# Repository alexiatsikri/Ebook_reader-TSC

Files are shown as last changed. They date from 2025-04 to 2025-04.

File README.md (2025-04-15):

# Ebook_reader-TSC

## Pasi de implementare
1. Analiza documentatiei initiale
- Am urmarit schematicul si board layout-ul furnizate de profesor.
- Pe baza acestora, am reprodus designul electronic in Fusion Electronics, atat schematicul, cat si placa PCB.
2. Plasarea componentelor in PCB
- Am inceput sa asez componentele pe placa, respectand pozitionarea si orientarea optima pentru un traseu eficient si functional.
3. Rutarea traseelor
- Am efectuat manual rutarea traseelor de putere, pentru a ma asigura ca acestea sunt robuste si bine dimensionate.
- Pentru restul conexiunilor, am utilizat functia de autorouting pe ambele straturi: top si bottom.
- Am adaugat polygon pour pentru ambele straturi, pentru a realiza plane de masa.
4. Optimizarea layout-ului
- Am utilizat vias pentru a conecta planele de masa intre straturi si a completa zonele neconectate.
- Am aplicat via stitching pentru a imbunatati integritatea electrica.
5. Generarea modelului 3D al placii
- Am creat modelul 3D al placii pe baza designului 2D.
- Pentru aceasta, am cautat, descarcat si importat manual fiecare componenta 3D, apoi le-am pozitionat conform plasamentului din PCB-ul 2D.
- Pentru componenta test pad, nu am gasit un model 3D disponibil online, asa ca am fost nevoita sa il modelez manual, pentru a putea reprezenta corect placa in ansamblul 3D.
6. Integrarea in ansamblul final – Openbook Enclosure
- Am importat modelul 3D al placii in fisierul principal al carcasei: Openbook Enclosure.
- In acest fisier am plasat toate componentele in carcasa finala, astfel incat sa asigur o potrivire optima si functionala.
- Am desenat manual display-ul si bateria, pentru a le integra in ansamblu si a obtine o reprezentare cat mai realista a produsului final.

## Block Diagram

Diagrama bloc

## Bill of Materials
| Componenta | Link | Datasheet |
|---|---|---|
| Buton | [Model](https://industry.panasonic.com/global/en/products/control/switch/light-touch/number/evqpuj02k) | [Datasheet](https://www.lcsc.com/datasheet/lcsc_datasheet_2201121800_PANASONIC-EVQPUJ02K_C2936858.pdf) |
| Capacitor | [Model](https://componentsearchengine.com/part-view/R0402%201%25%20100%20K%20(RC0402FR-07100KL)/YAGEO) | [Datasheet](//efaidnbmnnnibpcajpcglclefindmkaj/https://www.resistor.com/assets/pdf/0402tstd.pdf) |
| CPH3225A | [Model](https://www.snapeda.com/parts/CPH3225A/Seiko+Instruments/view-part/?ref=eda) | [Datasheet](https://octopart.com/datasheet/cph3225a-seiko-25340571) |
| EVQPUJ02K | [Model](https://industry.panasonic.com/global/en/products/control/switch/light-touch/number/evqpuj02k) | [Datasheet](https://www.lcsc.com/datasheet/lcsc_datasheet_2201121800_PANASONIC-EVQPUJ02K_C2936858.pdf) |
| KP-1608SURCK | [Model](https://www.snapeda.com/parts/KP-1608SURCK/Kingbright/view-part/?ref=search&t=LED%200603) | [Datasheet](//efaidnbmnnnibpcajpcglclefindmkaj/https://media.elv.com/file/107153_led_surck1608_data.pdf) |
| USBLC6-2SC6Y | [Model](https://www.snapeda.com/parts/USBLC6-2SC6Y/STMicroelectronics/view-part/?ref=eda) | [Datasheet](https://www.digikey.com/en/htmldatasheets/production/1375342/0/0/1/usblc6-2sc6y) |
| SD0805S020S1R0 | [Model](https://ro.mouser.com/ProductDetail/KYOCERA-AVX/SD0805S020S1R0?qs=jCA%252BPfw4LHbpkAoSnwrdjw%3D%3D) | [Datasheet](https://www.alldatasheet.com/view.jsp?Searchword=SD0805S&sField=2) |
| PGB1010603MR | [Model](https://www.snapeda.com/parts/PGB1010603MR/Littelfuse/view-part/?ref=eda) | [Datasheet](https://www.alldatasheet.com/view.jsp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) |
| BD5229G-TR  | [Model](https://componentsearchengine.com/part-view/BD5229G-TR/ROHM%20Semiconductor) | [Datasheet](https://www.lcsc.com/datasheet/lcsc_datasheet_2201131330_ROHM-Semicon-BD5229G-TR_C962636.pdf) |
| XC6220A331MR-G | [Model](https://componentsearchengine.com/part-view/XC6220A331MR-G/Torex) | [Datasheet](https://www.alldatasheet.com/view.jsp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) |
| XC6220A331MR-G | [Model](https://componentsearchengine.com/part-view/XC6220A331MR-G/Torex) | [Datasheet](https://www.alldatasheet.com/view.jsp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) |
| USB4110-GF-A  | [Model](https://componentsearchengine.com/part-view/USB4110-GF-A/GCT%20(GLOBAL%20CONNECTOR%20TECHNOLOGY)) | [Datasheet](//efaidnbmnnnibpcajpcglclefindmkaj/https://gct.co/files/drawings/usb4110.pdf) |
| Adafruit | [Model](https://eu.mouser.com/ProductDetail/Adafruit/4208?qs=PzGy0jfpSMtbScLbr0L5dw%3D%3D) | [Datasheet](https://www.arrow.com/en/manufacturers/adafruit-industries/datasheets) |
| Bobina | [Model](https://store.comet.srl.ro/Catalogue/Product/43497/) | [Datasheet](https://www.scribd.com/document/814581278/Datasheet-Bobina) |
| PFMF | [Model](https://www.mouser.co.uk/ProductDetail/EPCOS-TDK/B72520T0350K062?qs=dEfas%2FXlABIszF52uu7vrg%3D%3D) | [Datasheet](https://ro.mouser.com/c/ds/circuit-protection/thermistors/resettable-fuses-pptc/?m=Schurter&series=PFMF) |
| DMG2305UX-7 | [Model](https://componentsearchengine.com/part-view/DMG2305UX-7/Diodes%20Incorporated) | [Datasheet](//efaidnbmnnnibpcajpcglclefindmkaj/https://www.mouser.com/datasheet/2/115/DMG2305UX-266242.pdf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) |
| Si1308EDL-T1-GE3 | [Model](https://componentsearchengine.com/part-view/SI1308EDL-T1-GE3/Vishay) | [Datasheet](https://www.alldatasheet.com/view.jsp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) |
| R0402 | [Model](https://componentsearchengine.com/part-view/R0402%201%25%20100%20K%20(RC0402FR-07100KL)/YAGEO) | [Datasheet](//efaidnbmnnnibpcajpcglclefindmkaj/https://www.resistor.com/assets/pdf/0402tstd.pdf) |
| BME680 | [Model](https://www.snapeda.com/parts/BME680/Bosch/view-part/?welcome=home) | [Datasheet](//efaidnbmnnnibpcajpcglclefindmkaj/https://www.bosch-sensortec.com/media/boschsensortec/downloads/datasheets/bst-bme680-ds001.pdf) |
| SMD Solder | [Model](https://grabcad.com/library/solder-jumpers-1) | [Datasheet]() |
| W25Q512JVEIQ | [Model](https://www.snapeda.com/parts/ESP32-C6-WROOM-1-N8/Espressif+Systems/view-part/?ref=eda) | [Datasheet](//efaidnbmnnnibpcajpcglclefindmkaj/https://www.mouser.com/datasheet/2/949/W25Q512JV_SPI_RevB_06252019_KMS-2487502.pdf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) |
| ESP32-C6-WROOM-1-N8 | [Model](https://www.snapeda.com/parts/ESP32-C6-WROOM-1-N8/Espressif+Systems/view-part/?ref=eda) | [Datasheet](//efaidnbmnnnibpcajpcglclefindmkaj/https://www.mouser.com/catalog/specsheets/Espressif_ESP32_C6_WROOM_1%20_Datasheet_V0.1_PRELIMINARY_en.pdf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) |
| DS3231SN# | [Model](https://www.snapeda.com/parts/DS3231SN%23/Analog+Devices/view-part/?ref=eda) | [Datasheet](https://www.alldatasheet.com/view.jsp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) |
| MAX17048G+T10 | [Model](https://www.snapeda.com/parts/MAX17048G+T10/Analog+Devices/view-part/?ref=eda) | [Datasheet](https://www.alldatasheet.com/view.jsp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) |
| MCP73831T-5ACI/OT | [Model](https://www.mouser.co.uk/ProductDetail/Microchip-Technology/MCP73831T-5ACI-OT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) | [Datasheet](//efaidnbmnnnibpcajpcglclefindmkaj/https://ww1.microchip.com/downloads/en/DeviceDoc/MCP73831-Family-Data-Sheet-DS20001984H.pdf) |

## Functionalitate Hardware

Proiectul are la baza un circuit electronic compact, conceput pentru un dispozitiv de tip E-Book. Componentele principale sunt:

###  USB-C + Protectie ESD
- Asigura alimentarea dispozitivului.
- Se conecteaza prin interfata USB.
- Include protectie ESD pentru siguranta suplimentara.

###  SD Card
- Serveste ca mediu de stocare pentru cartile electronice.
- Functioneaza la 3.3V si comunica prin SPI cu microcontrollerul.

###  E-Paper Display + Module Asociate
- Include E-Paper Drive Circuit, Display Header si modulul EPD Power.
- Display Header se conecteaza la microcontroller prin SPI.
- EPD Power genereaza tensiunile necesare, iar Drive Circuit furnizeaza semnalele de control.
- Consum maxim la refresh: 30mA (alb-negru) / 60mA (color); consum zero in inactivitate.

### Senzor de Mediu - BME688
- Masoara temperatura, umiditate, presiune si calitatea aerului.
- Comunica prin I2C si functioneaza la 3.3V.
- Consum: <1uA in standby, 1–2mA in functionare.

### Modul RTC - DS3231SN
- Pastreaza ora si data curenta chiar si cu microcontrollerul oprit.
- Functioneaza pe baterie, cristal integrat de 32KHz.
- Comunica prin I2C.
- Consum: 150uA normal, 1uA pe baterie.

###  Memorie Flash Externa - 64MB NOR
- Extinde spatiul de stocare al microcontrollerului.
- Interfata SPI.
- Consum redus: 30–50mA la scriere/stergere, 10–20uA in standby.

###  Regulator de Tensiune LDO
- Asigura 3.3V pentru microcontroller.
- Consum foarte mic (~8uA activ), ideal pentru dispozitive pe baterii.

###  Supraveghetor de Tensiune
- Monitorizeaza stabilitatea tensiunii.
- Previne pornirea in conditii de tensiune necorespunzatoare.

###  Conector Qwiic/Stemma QT
- Permite conectarea facila a senzorilor prin I2C.
- Suporta conectarea in lant fara cabluri suplimentare.

###  Controler Baterie Li-Po
- Gestioneaza incarcarea/descarcarea bateriei.
- Previne suprasarcina si descarcarea profunda.

## Microcontroller - ESP32-C5

Platforma principala este modulul **ESP32-C5-WROOM**, un microcontroller performant cu consum redus, conectivitate moderna si suport pentru multiple interfete:

- **Consum energetic estimat:**
  - Activ: 100–120mA
  - Idle: 10–15mA
  - Deep Sleep: 10–20uA
- **Conectivitate:** Wi-Fi 6 (2.4 GHz), Bluetooth 5, USB nativ
- **Interfete:** GPIO, SPI, I2C, UART

### Conexiuni ESP32-C6

| Functie | Pini ESP32-C6 |
|---|---|
| Alimentare & Reset | 3V3, GND, EN |
| USB-C | GPIO13 (USB_D+), GPIO14 (USB_D-) |
| SD Card (SPI) | GPIO27 (MISO), GPIO7 (MOSI), GPIO6 (SCK), GPIO4 (SS_SD) |
| E-Paper Display | GPIO11 (EPD_CS), GPIO5 (EPD_DC), GPIO21 (EPD_RST), GPIO26 (EPD_BUSY) |
| Senzor BME688 (I2C) | GPIO19 (SDA), GPIO20 (SCL), GPIO17 (I2C_PW) |
| UART | TXD0, RXD0 |
| Flash Extern | FLASH_CS |
| Alte functii | IO/BOOT, RTC_PWM, RTC_RST, INT_RTC |

## Design PCB & Amplasare Componente

Amplasarea componentelor pe placa a fost realizata cu grija, respectand bune practici pentru performanta si fiabilitate:

- **ESP32-C6** – pozitionat sus, cu antena orientata spre exterior si zona PCB decupata pentru semnal clar.
- **USB-C** – centrat in partea de jos, aliniat cu carcasa.
- **Display Header** – lateral, cu decupaj dedicat pentru ribbon.
- **Qwiic Connector** – pe margine, spatiu suficient pentru conectare facila.
- **Baterie** – PCB decupat pentru a acomoda dimensiunea bateriei Li-Po.
  
 ## Erori

  La editarea PCB-ului am intampinat urmatoarele erori:
  
- Smd, Copper Width - Net Class: 1 POWER
- Smd-Hole, Board Outline Clearance
 Smd-Hole, Board Outline Clearance

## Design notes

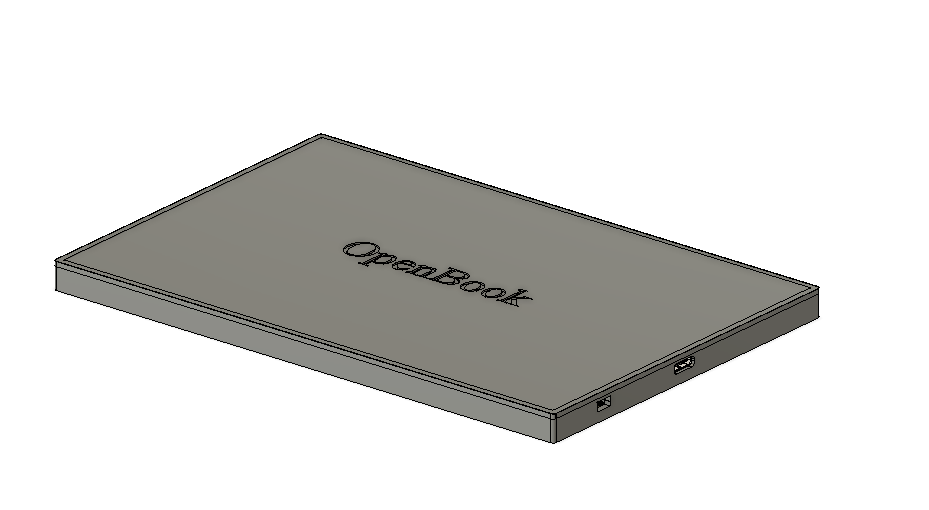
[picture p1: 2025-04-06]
Images/Top-board.png

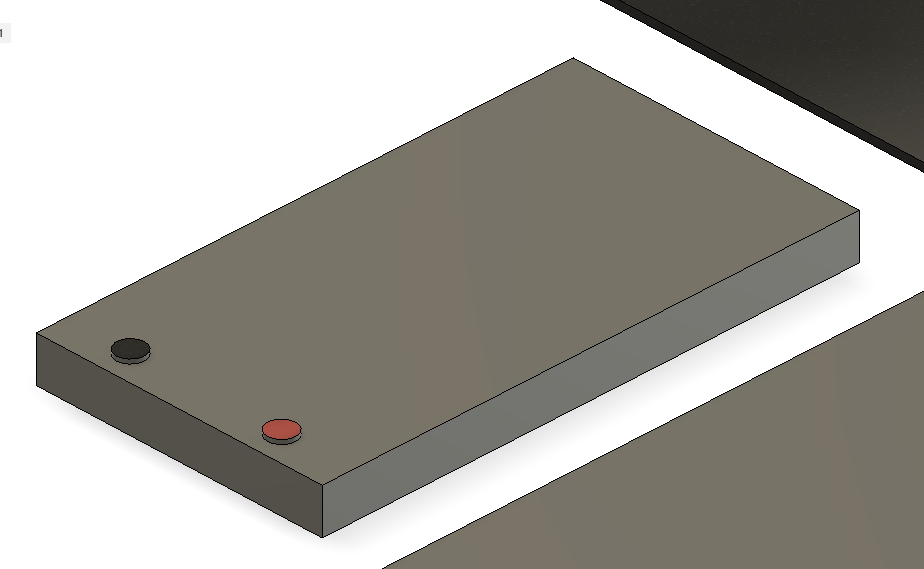
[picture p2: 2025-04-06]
Images/Battery.png

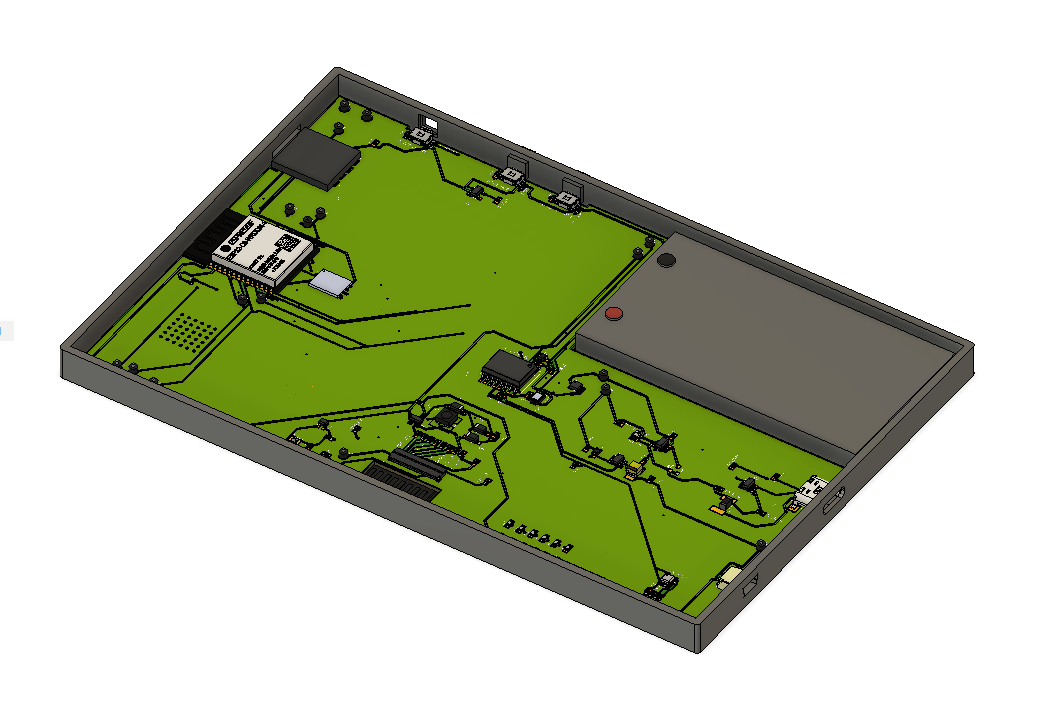
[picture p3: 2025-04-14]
Images/Top-board-no-lid-UPDATE.png

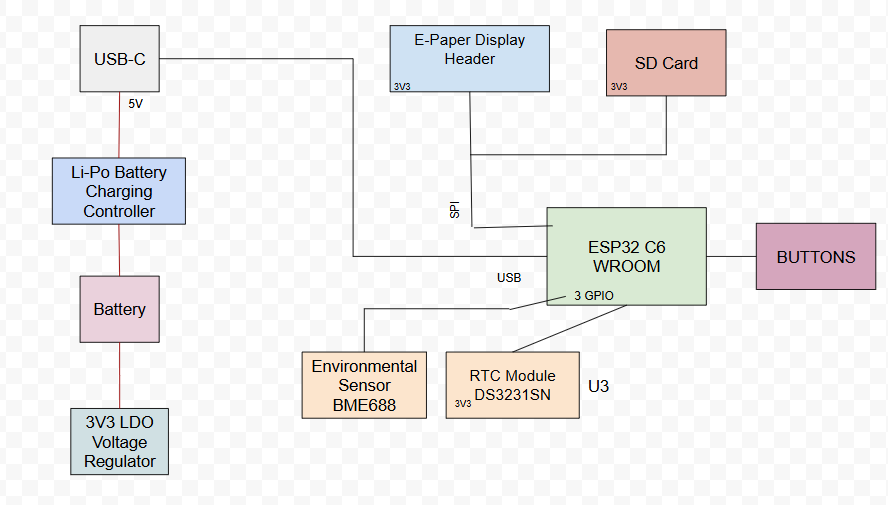
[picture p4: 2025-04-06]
Images/Diagrama bloc.png

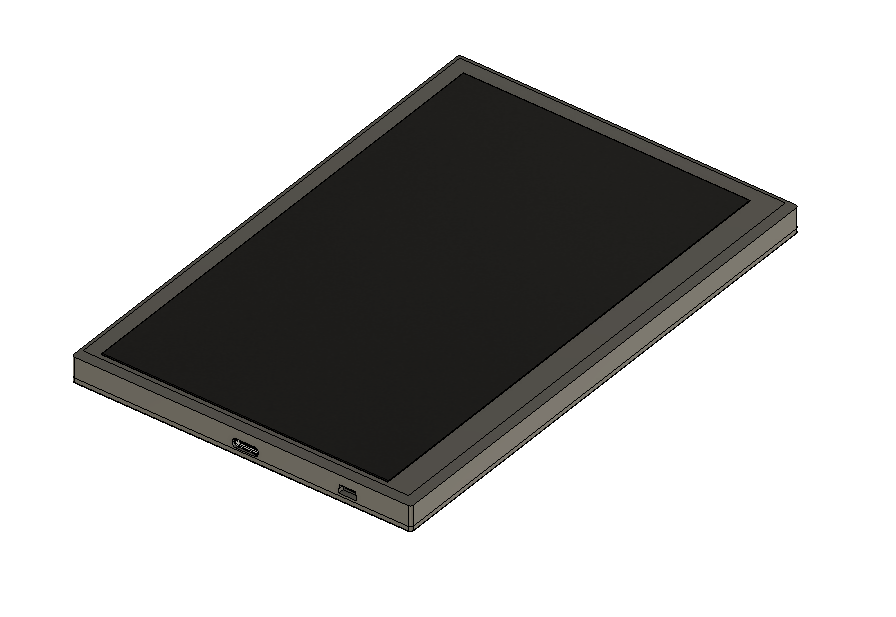
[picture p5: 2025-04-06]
Images/Bottom-board.png

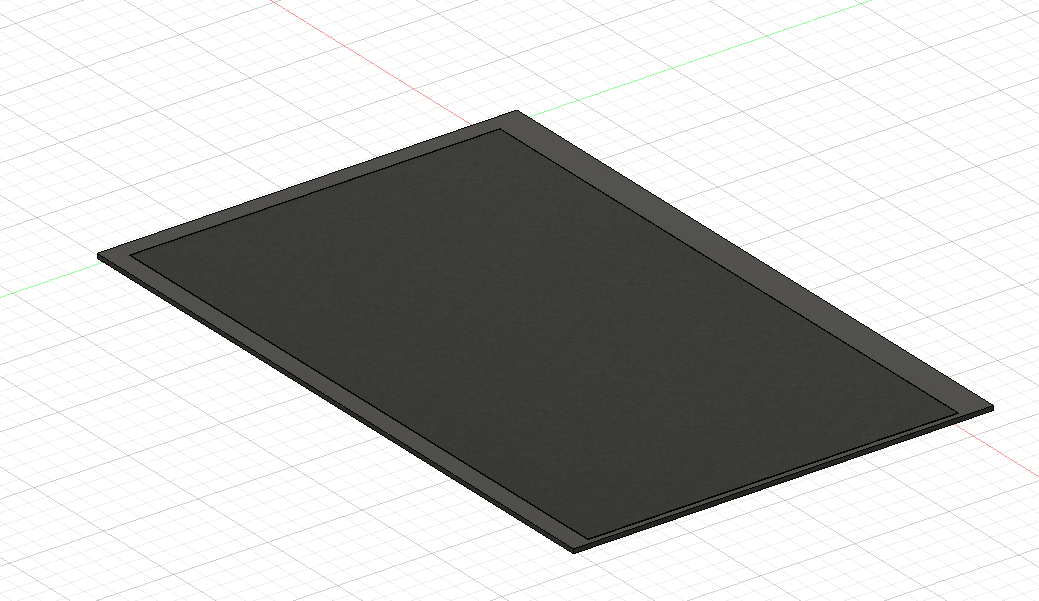
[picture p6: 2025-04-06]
Images/Display.png

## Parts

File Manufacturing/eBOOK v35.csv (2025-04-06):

Qty | Value | Device | Package | Parts | Description | ARROW_PART_NUMBER | ARROW_PRICE-STOCK | AVAILABILITY | CENTROID_NOT_SPECIFIED | CHECK_PRICES | COPYRIGHT | DATASHEET | DESCRIPTION | DIGIKEY_DESCRIPTION | DIGIKEY_PART_NUMBER | HEIGHT | LEAD_FREE | MANUFACTURER_NAME | MANUFACTURER_PART_NUMBER | MF | MFR_NAME | MOUSER_PART_NUMBER | MOUSER_PRICE-STOCK | MOUSER_TESTING_PART_NUMBER | MOUSER_TESTING_PRICE-STOCK | MP | MPN | PACKAGE | POPULARITY | PREFIX | PRICE | PROD_ID | PURCHASE-URL | ROHS | SNAPEDA_LINK | SPICEMODEL | SPICEPREFIX | TEMPERATURE_RANGE_HIGH | TEMPERATURE_RANGE_LOW | TP_SIGNAL_NAME | VALUE
1 |  | ADAFRUIT_LEDCHIP-LED0603 | ADAFRUIT_CHIP-LED0603 | CHG_LED | LED |  |  |  |  | https://www.snapeda.com/parts/KP-1608SURCK/Kingbright/view-part/?ref=search&t=LED%200603
1 |  | SJ | SJ | SJ1 | SMD solder JUMPER |  |  |  |  | https://grabcad.com/library/solder-jumpers-1 |  |  |  |  |  |  |  |  |  |  |  |  |  |  |  |  |  |  | 3
1 | 0.1uF/50V | ESP32_WROVER_EAGLE-LTSPICE_CC0402 | ESP32_WROVER_EAGLE-LTSPICE_C0402 | EPD_C5 | CAPACITOR, European symbol |  |  |  |  | https://componentsearchengine.com/part-view/CC0402MRX5R5BB106/YAGEO |  |  |  |  |  |  |  |  |  |  |  |  |  |  |  |  |  |  |  |  |  |  |  |  |  | NONE | C
1 | 0.47 | ESP32_WROVER_EAGLE-LTSPICE_RR0402 | ESP32_WROVER_EAGLE-LTSPICE_R0402 | R3 | RESISTOR, European symbol |  |  |  |  | https://componentsearchengine.com/part-view/R0402%201%25%20100%20K%20(RC0402FR-07100KL)/YAGEO |  |  |  |  |  |  |  |  |  |  |  |  |  |  |  |  |  |  |  |  |  |  |  |  |  | NONE | R
1 | 100K | ESP32_WROVER_EAGLE-LTSPICE_RR0402 | ESP32_WROVER_EAGLE-LTSPICE_R0402 | R1_PWRUSB | RESISTOR, European symbol |  |  |  |  | https://componentsearchengine.com/part-view/R0402%201%25%20100%20K%20(RC0402FR-07100KL)/YAGEO |  |  |  |  |  |  |  |  |  |  |  |  |  |  |  |  |  |  |  |  |  |  |  |  |  | NONE | R
8 | 100nF | ESP32_WROVER_EAGLE-LTSPICE_CC0402 | ESP32_WROVER_EAGLE-LTSPICE_C0402 | C1, C2, C4_USB, C6, C8, C9, C10, C_DELAY | CAPACITOR, European symbol |  |  |  |  | https://componentsearchengine.com/part-view/CC0402MRX5R5BB106/YAGEO |  |  |  |  |  |  |  |  |  |  |  |  |  |  |  |  |  |  |  |  |  |  |  |  |  | NONE | C
1 | 100uF TANT | RCL_CPOL-EUCT3528 | RCL_CT3528 | C3 | POLARIZED CAPACITOR, European symbol |  |  |  |  | https://stud33302.autodesk360.com/g/shares/SH30dd5QT870c25f12fc6065d74bcaa3bf24 |  |  |  |  |  |  |  |  |  |  |  |  |  |  |  |  |  |  | 0 |  |  |  |  |  |  |  | C
16 | 10K | ESP32_WROVER_EAGLE-LTSPICE_RR0402 | ESP32_WROVER_EAGLE-LTSPICE_R0402 | R1, R1_PINH, R1_PINH1, R2-PINH, R2-PINH1, R4, R5, R6, R7, R8, R9, R10, R_BOOT, R_CHANGE, R_CL1, R_RESET | RESISTOR, European symbol |  |  |  |  | https://componentsearchengine.com/part-view/R0402%201%25%20100%20K%20(RC0402FR-07100KL)/YAGEO |  |  |  |  |  |  |  |  |  |  |  |  |  |  |  |  |  |  |  |  |  |  |  |  |  | NONE | R
1 | 10uF | ESP32_WROVER_EAGLE-LTSPICE_CC0402 | ESP32_WROVER_EAGLE-LTSPICE_C0402 | C7 | CAPACITOR, European symbol |  |  |  |  | https://componentsearchengine.com/part-view/CC0402MRX5R5BB106/YAGEO |  |  |  |  |  |  |  |  |  |  |  |  |  |  |  |  |  |  |  |  |  |  |  |  |  | NONE | C
1 | 112A-TAAR-R03_ATTEND | 112A-TAAR-R03_ATTEND | 112ATAARR03ATTEND | J4 | Micro SD Card Socket, Push-Push Type, Top Mount, SMT, H=1.83mm, 10u |  |  |  |  | https://www.snapeda.com/parts/112A-TAAR-R03/Attend/view-part/ |  |  | Micro SD Card Socket | Push-Push Type | Top Mount | SMT | H=1.83mm | 10u |  |  | 1.9mm |  | ATTEND | 112A-TAAR-R03 ATTEND
1 | 15 | ESP32_WROVER_EAGLE-LTSPICE_RR0402 | ESP32_WROVER_EAGLE-LTSPICE_R0402 | R_CAPACITOR | RESISTOR, European symbol |  |  |  |  | https://componentsearchengine.com/part-view/R0402%201%25%20100%20K%20(RC0402FR-07100KL)/YAGEO |  |  |  |  |  |  |  |  |  |  |  |  |  |  |  |  |  |  |  |  |  |  |  |  |  | NONE | R
1 | 1uF | ESP32_WROVER_EAGLE-LTSPICE_CC0402 | ESP32_WROVER_EAGLE-LTSPICE_C0402 | C5 | CAPACITOR, European symbol |  |  |  |  | https://componentsearchengine.com/part-view/CC0402MRX5R5BB106/YAGEO |  |  |  |  |  |  |  |  |  |  |  |  |  |  |  |  |  |  |  |  |  |  |  |  |  | NONE | C
9 | 1uF/50V | ESP32_WROVER_EAGLE-LTSPICE_CC0402 | ESP32_WROVER_EAGLE-LTSPICE_C0402 | EPD_C1, EPD_C2, EPD_C6, EPD_C7, EPD_C8, EPD_C9, EPD_C10, EPD_C11, EPD_C12 | CAPACITOR, European symbol |  |  |  |  | https://componentsearchengine.com/part-view/CC0402MRX5R5BB106/YAGEO |  |  |  |  |  |  |  |  |  |  |  |  |  |  |  |  |  |  |  |  |  |  |  |  |  | NONE | C
1 | 2.2 | ESP32_WROVER_EAGLE-LTSPICE_RR0402 | ESP32_WROVER_EAGLE-LTSPICE_R0402 | R2 | RESISTOR, European symbol |  |  |  |  | https://componentsearchengine.com/part-view/R0402%201%25%20100%20K%20(RC0402FR-07100KL)/YAGEO |  |  |  |  |  |  |  |  |  |  |  |  |  |  |  |  |  |  |  |  |  |  |  |  |  | NONE | R
1 | 200 | ESP32_WROVER_EAGLE-LTSPICE_RR0402 | ESP32_WROVER_EAGLE-LTSPICE_R0402 | R1_BAT | RESISTOR, European symbol |  |  |  |  | https://componentsearchengine.com/part-view/R0402%201%25%20100%20K%20(RC0402FR-07100KL)/YAGEO |  |  |  |  |  |  |  |  |  |  |  |  |  |  |  |  |  |  |  |  |  |  |  |  |  | NONE | R
2 | 20V/4.2A/52mO/1.4W | ESP32_WROVER_SPARKFUN-DISCRETESEMI_MOSFET_PCH-DMG2305UX-7 | ESP32_WROVER_SPARKFUN-DISCRETESEMI_SOT23-3 | Q1, Q2 | P-channel MOSFETs |  |  |  |  | https://www.snapeda.com/parts/DMG2305UX-7/Diodes%20Inc./view-part/ |  |  |  |  |  |  |  |  |  |  |  |  |  |  |  |  |  |  |  |  |  | TRAN-14388 |  |  |  |  |  |  |  |  | 20V/4.2A/52mO/1.4W
1 | 2K | ESP32_WROVER_EAGLE-LTSPICE_RR0402 | ESP32_WROVER_EAGLE-LTSPICE_R0402 | R2_BAT | RESISTOR, European symbol |  |  |  |  | https://componentsearchengine.com/part-view/R0402%201%25%20100%20K%20(RC0402FR-07100KL)/YAGEO |  |  |  |  |  |  |  |  |  |  |  |  |  |  |  |  |  |  |  |  |  |  |  |  |  | NONE | R
5 | 4.7uF | ESP32_WROVER_EAGLE-LTSPICE_CC0402 | ESP32_WROVER_EAGLE-LTSPICE_C0402 | C1_BAT, C1_BAT1, C1_BAT2, C2_BAT, C5_USB | CAPACITOR, European symbol |  |  |  |  | https://componentsearchengine.com/part-view/CC0402MRX5R5BB106/YAGEO |  |  |  |  |  |  |  |  |  |  |  |  |  |  |  |  |  |  |  |  |  |  |  |  |  | NONE | C
1 | 4.7uF/25V | ESP32_WROVER_EAGLE-LTSPICE_CC0402 | ESP32_WROVER_EAGLE-LTSPICE_C0402 | C4 | CAPACITOR, European symbol |  |  |  |  | https://componentsearchengine.com/part-view/CC0402MRX5R5BB106/YAGEO |  |  |  |  |  |  |  |  |  |  |  |  |  |  |  |  |  |  |  |  |  |  |  |  |  | NONE | C
2 | 5k1 | ESP32_WROVER_EAGLE-LTSPICE_RR0402 | ESP32_WROVER_EAGLE-LTSPICE_R0402 | R2-USB, R2-USB1 | RESISTOR, European symbol |  |  |  |  | https://componentsearchengine.com/part-view/R0402%201%25%20100%20K%20(RC0402FR-07100KL)/YAGEO |  |  |  |  |  |  |  |  |  |  |  |  |  |  |  |  |  |  |  |  |  |  |  |  |  | NONE | R
1 | 68uH | 744043680IND_4828-WE-TPC_WRE | IND_4828-WE-TPC_WRE | L1 |  |  |  |  |  | https://www.digikey.ro/en/models/2931664 | Copyright (C) 2024 Ultra Librarian. All rights reserved. |  |  |  |  |  |  |  | 744043680 |  | Wurth Electronics
1 | BD5229G-TR | BD5229G-TR | SOT95P280X125-5N | IC1 | Voltage Detector with Adjustable Delay Time: CMOS processes are utilized to develop high precision, low current consumption CMOS reset ICs that allow arbitrary setting of the delay time. The extensive lineup includes both Nch Open Drain and CMOS output types in a wide range of detection voltages (from 2.3V to 6.0V, in 0.1V steps), enabling selection of the ideal solution based on customer requirements. In addition, the entire series is of course both lead-free and RoHS-compliant. |  |  |  |  | https://componentsearchengine.com/part-view/BD5229G-TR/ROHM%20Semiconductor |  |  | Voltage Detector with Adjustable Delay Time: CMOS processes are utilized to develop high precision | low current consumption CMOS reset ICs that allow arbitrary setting of the delay time. The extensive lineup includes both Nch Open Drain and CMOS output types in a wide range of detection voltages (from 2.3V to 6.0V | in 0.1V steps) | enabling selection of the ideal solution based on customer requirements. In addition | the entire series is of course both lead-free and RoHS-compliant. |  |  | 1.25mm |  | ROHM Semiconductor | BD5229G-TR |  |  | 755-BD5229G-TR | https://www.mouser.co.uk/ProductDetail/ROHM-Semiconductor/BD5229G-TR?qs=4kLU8WoGk0vvnhrrYwdszw%3D%3D
3 | BUTTON_CUSYOMV1 | BUTTON_CUSYOMV1 | MYBUTTON | BOOT_BUTTON, CHANGE_BUTTON, RESET_BUTTON |  |  |  |  |  | https://industry.panasonic.com/global/en/products/control/switch/light-touch/number/evqpuj02k
1 | CPH3225A | CPH3225A | CAPCP3225X100N | C10_SUPERCAP | Cap 0.011F 3.3V 1210 Flat Check availability |  |  | Not in stock |  | https://www.snapeda.com/parts/CPH3225A/Seiko+Instruments/view-part/?ref=eda |  |  | 11 mF (EDLC) Supercapacitor 3.3 V 1210 (3225 Metric) - - |  |  |  |  |  |  | Seiko Instruments |  |  |  |  |  | CPH3225A |  | 1210 Seiko |  |  | None |  | https://www.snapeda.com/api/url_track_click_mouser/?unipart_id=562593&manufacturer=Seiko Instruments&part_name=CPH3225A&search_term=None |  | https://www.snapeda.com/parts/CPH3225A/Seiko+Instruments/view-part/?ref=snap
1 | DS3231SN# | DS3231SN# | SOIC127P1032X265-16N | U3 | Check availability |  |  | Not in stock |  | https://www.snapeda.com/parts/DS3231SN%23/Maxim+Integrated/view-part/?ref=eda |  |  | Real Time Clock (RTC) IC Clock/Calendar I2C | 2-Wire Serial 16-SOIC (0.295 | 7.50mm Width) |  |  |  |  |  |  | Maxim Integrated Products |  |  |  |  |  | DS3231SN# |  | None |  |  | None |  |  |  | https://www.snapeda.com/parts/DS3231SN%23/Maxim+Integrated/view-part/?ref=snap
1 | ESP32-C6-WROOM-1-N8 | ESP32-C6-WROOM-1-N8 | XCVR_ESP32-C6-WROOM-1-N8 | U2 | Check availability |  |  | In Stock |  | https://www.snapeda.com/parts/ESP32-C6-WROOM-1-N8/Espressif+Systems/view-part/?ref=eda |  |  | Multiprotocol Modules ESP32-C6 module | Wi-Fi 6 in 2.4 GHz band | Bluetooth 5 | Zigbee 3.0 and Thread. ESP34-WROOM Compatible - ENGINEERING SAMPLE |  |  |  |  |  |  | Espressif Systems |  |  |  |  |  | ESP32-C6-WROOM-1-N8 |  | None |  |  | None |  |  |  | https://www.snapeda.com/parts/ESP32-C6-WROOM-1-N8/Espressif+Systems/view-part/?ref=snap
1 | ESP32C6_VARISTORCN1812 | ESP32C6_VARISTORCN1812 | ESP32C6_VARISTOR_CT/CN1812 | PFMF.050.1 | VARISTOR |  |  |  |  | https://componentsearchengine.com/part-view/PFMF.050.2/SCHURTER |  |  |  |  |  |  |  |  |  |  |  |  |  |  |  |  |  |  | 0
2 | ESP32_WROVER_AVX---SD0805S020S1R0_AVX_SD0805S020S1R0_0_0AVX_SD0805S020S1R0_0_0 | ESP32_WROVER_AVX---SD0805S020S1R0_AVX_SD0805S020S1R0_0_0AVX_SD0805S020S1R0_0_0 | ESP32_WROVER_AVX---SD0805S020S1R0_AVX_SD0805S020S1R0_0 | D2, D7 | Schottky Barrier Rectifier Diode |  |  |  | No | https://eu.mouser.com/ProductDetail/KYOCERA-AVX/SD0805S020S1R0?qs=jCA%252BPfw4LHbpkAoSnwrdjw%3D%3D |  | http://datasheets.avx.com/schottky.pdf |  | DIODE SCHOTTKY 20V 1A 0805 | 478-7800-1-ND |  | yes |  |  | AVX |  | 581-SD0805S020S1R0 |  |  |  |  |  | 0805 (2012 metric) |  | D |  |  |  | yes |  |  |  | +125°C | -55°C
1 | ESP32_WROVER_BME680_BME680 | ESP32_WROVER_BME680_BME680 | ESP32_WROVER_BME680_PSON80P300X300X100-8N | SENSOR2 | Integrated Environmental Unit |  |  | Unavailable |  | http://snapeda.com/parts/BME680/Bosch/view-part/?welcome=home |  |  | Integrated Environmental Unit |  |  |  |  |  |  | Bosch Sensortec |  |  |  |  |  | BME680 |  | LGA-8 Bosch Tools |  |  | None
1 | ESP32_WROVER_SPARKFUN-IC-POWER_MCP73831 | ESP32_WROVER_SPARKFUN-IC-POWER_MCP73831 | ESP32_WROVER_SPARKFUN-IC-POWER_SOT23-5 | U5 | MCP73831T Li-Ion, Li-Pol Controller |  |  |  |  | https://componentsearchengine.com/part-view/MCP73831-2ACI%2FOT/Microchip |  |  |  |  |  |  |  |  |  |  |  |  |  |  |  |  |  |  |  |  |  | IC-09995
1 | FH34SRJ-24S-0.5SH_99_ | FH34SRJ-24S-0.5SH_99_ | FH34SRJ24S05SH99 | J1 | (0.50mm) Surface Mount, Right Angle |  |  |  |  | https://ro.mouser.com/ProductDetail/Hirose-Connector/FH34SRJ-24S-0.5SH99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 |  |  | 24 Position FFC | FPC Connector Contacts | (0.50mm) Surface Mount | Right Angle |  |  | 1.1mm |  | Hirose | FH34SRJ-24S-0.5SH(99) |  |  | 798-FH34SRJ24S05SH99 | https://www.mouser.co.uk/ProductDetail/Hirose-Connector/FH34SRJ-24S-0.5SH99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
1 | MAX17048G+T10 | MAX17048G+T10 | SON50P200X200X80-9N | U4 | Check availability |  |  | In Stock |  | https://www.snapeda.com/parts/MAX17048G+T10/Analog+Devices/view-part/?ref=eda |  |  | 3µA 1-Cell/2-Cell Fuel Gauge with ModelGauge |  |  |  |  |  |  | Analog Devices |  |  |  |  |  | MAX17048G+T10 |  | TDFN-8 Maxim |  |  | None |  | https://www.snapeda.com/api/url_track_click_mouser/?unipart_id=329239&manufacturer=Analog Devices&part_name=MAX17048G+T10&search_term=None |  | https://www.snapeda.com/parts/MAX17048G+T10/Analog+Devices/view-part/?ref=snap
3 | MBR0530 | MBR0530 | SOD3716X135N | D3, D4, D5 | ON SEMICONDUCTOR - MBR0530 - DIODE, SCHOTTKY, 0.5A, 30V, SOD-123 |  |  | In Stock |  | https://www.snapeda.com/parts/MBR0530/Onsemi/view-part/?ref=eda |  |  | Diode Schottky 30 V 500mA Surface Mount SOD-123 |  |  |  |  |  |  | ON Semiconductor |  |  |  |  |  | MBR0530 |  | SOD-123-2 ON Semiconductor |  |  | None |  | https://www.snapeda.com/api/url_track_click_mouser/?unipart_id=179458&manufacturer=ON Semiconductor&part_name=MBR0530&search_term=None |  | https://www.snapeda.com/parts/MBR0530/Onsemi/view-part/?ref=snap
6 | PGB1010603MR | PGB1010603MR | DIOC1608X36N | D6, D8, D9, D10, D11, D12 | Check availability |  |  | In Stock |  | https://www.snapeda.com/parts/PGB1010603MR/Littelfuse/view-part/?ref=eda |  |  | 150V (Typ) Clamp - Ipp Tvs Diode Surface Mount 0603 (1608 Metric) |  |  |  |  |  |  | Littelfuse Inc. |  |  |  |  |  | PGB1010603MR |  | 0603 Littelfuse Inc. |  |  | None |  | https://www.snapeda.com/api/url_track_click_mouser/?unipart_id=5659453&manufacturer=Littelfuse Inc.&part_name=PGB1010603MR&search_term=None |  | https://www.snapeda.com/parts/PGB1010603MR/Littelfuse/view-part/?ref=snap
1 | QWIIC_RIGHT_ANGLE | QWIIC_CONNECTORJS-1MM | JST04_1MM_RA | J3 | SparkFun I2C Standard Qwiic Connector |  |  |  |  | https://componentsearchengine.com/part-view/PRT-14417/SparkFun |  |  |  |  |  |  |  |  |  |  |  |  |  |  |  |  |  |  |  |  |  | CONN-13694 |  |  |  |  |  |  |  |  | QWIIC_RIGHT_ANGLE
1 | SAMACSYS_PARTS_USB4110-GF-A | SAMACSYS_PARTS_USB4110-GF-A | SAMACSYS_PARTS_USB4110GFA | J2 | CONN USB 2.0 TYPE-C R/A SMT |  |  |  |  | https://componentsearchengine.com/part-view/USB4110-GF-A/GCT%20(GLOBAL%20CONNECTOR%20TECHNOLOGY) |  |  | CONN USB 2.0 TYPE-C R/A SMT |  |  | 3.26mm |  | GCT (GLOBAL CONNECTOR TECHNOLOGY) | USB4110-GF-A |  |  | 640-USB4110-GF-A | https://www.mouser.co.uk/ProductDetail/GCT/USB4110-GF-A?qs=KUoIvG%2F9IlYiZvIXQjyJeA%3D%3D
1 | SI1308EDL-T1-GE3 | SI1308EDL-T1-GE3 | SOT65P210X110-3N | Q3 | MOSFET N-Ch 30V 1.5A TrenchFET SC70 Vishay Si1308EDL-T1-GE3 N-channel MOSFET Transistor, 1.5 A, 30 V, 3-Pin SC-70 |  |  | In Stock |  | https://www.snapeda.com/parts/SI1308EDL-T1-GE3/Vishay+Siliconix/view-part/?ref=eda |  |  | Si1308EDL-T1-GE3 N-channel MOSFET Transistor | 1.5 A | 30 V | 3-Pin SC-70 | Siliconix / Vishay SI1308EDL-T1-GE3 |  |  |  |  |  |  | Vishay Siliconix |  |  |  |  |  | SI1308EDL-T1-GE3 |  | SOT-323 Vishay Semiconductor |  |  | None |  | https://www.snapeda.com/api/url_track_click_mouser/?unipart_id=274603&manufacturer=Vishay Siliconix&part_name=SI1308EDL-T1-GE3&search_term=None |  | https://www.snapeda.com/parts/SI1308EDL-T1-GE3/Vishay+Siliconix/view-part/?ref=snap
17 | TPTP20R | TPTP20R | TP20R | TP1, TP2, TP3, TP4, TP5, TP6, TP7, TP8, TP9, TP10, TP11, TP12, TP13, TP14, TP15, TP16, TP17 | Test pad |  |  |  |  |  |  |  |  |  |  |  |  |  |  |  |  |  |  |  |  |  |  |  | 2
1 | USBLC6-2SC6Y | USBLC6-2SC6Y | SOT95P280X145-6N | D1 | Low Cap. ESD Protection Auto SOT-23-6 STMicroelectronics USBLC6-2SC6Y, Dual Uni-Directional TVS Diode Array, 6-Pin SOT-23 |  |  | In Stock |  | https://www.snapeda.com/parts/USBLC6-2SC6Y/STMicroelectronics/view-part/?ref=eda |  |  | 17V Clamp 5A (8/20µs) Ipp Tvs Diode Surface Mount SOT-23-6 |  |  |  |  |  |  | STMicroelectronics |  |  |  |  |  | USBLC6-2SC6Y |  | SOT-23-6 STMicroelectronics |  |  | None |  |  |  | https://www.snapeda.com/parts/USBLC6-2SC6Y/STMicroelectronics/view-part/?ref=snap
1 | W25Q512JVEIQ | W25Q512JVEIQ | SON127P600X800X80-9N | U1 | Check availability |  |  | In Stock |  | https://www.snapeda.com/parts/W25Q512JVEIQ/Winbond+Electronics/view-part/?ref=eda |  |  | FLASH - NOR Memory IC 512Mb (64M x 8) SPI - Quad I/O 133 MHz 8-WSON (8x6) |  |  |  |  |  |  | Winbond Electronics |  |  |  |  |  | W25Q512JVEIQ |  | Package |  |  | None |  |  |  | https://www.snapeda.com/parts/W25Q512JVEIQ/Winbond+Electronics/view-part/?ref=snap
1 | XC6220A331MR-G | XC6220A331MR-G | SOT95P280X120-5N | IC4 | LDO Voltage Regulators |  |  |  |  | https://componentsearchengine.com/part-view/XC6220A331MR-G/Torex |  |  | LDO Voltage Regulators |  |  | 1.2mm |  | Torex | XC6220A331MR-G |  |  | 865-XC6220A331MR-G | https://www.mouser.co.uk/ProductDetail/Torex-Semiconductor/XC6220A331MR-G?qs=AsjdqWjXhJ8ZSWznL1J0gg%3D%3D

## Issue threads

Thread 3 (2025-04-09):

Overlap Schematic

urecheandreea, 2025-04-09:
Net-urile nu trebuie sa se suprapuna cu pinii , de aici si aceste warning-uri:

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
Incearca sa muti net-ul cu label cat sa nu se intersecteze cu pin-ul de deasupra.

Closed 2025-04-14.

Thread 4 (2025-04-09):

Copper Width Errors PCB

urecheandreea, 2025-04-09:
La erorile legate de copper width trebuie modificate marimile pad-urilor componentelor .
Le poti modifica cand dai **edit footprint** pe  componenta direct din PCB .

Selectezi pad-urile si le maresti dimensiunea  (cat vrei tu dar mai mare de 0.5 x 0.5 mm ) .
Apoi le poti da **replace** in PCB cu varianta modificata de tine.

Dupa ar trebui sa scapi de erorile de copper width atat la bobina cat si la U4.

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

Closed 2025-04-14.

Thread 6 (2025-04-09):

Via-Stitching 3D

urecheandreea, 2025-04-09:
In design-ul 3D , pare ca ai toata suprafata PCB-ului acoperita de vias-uri, ceea ce nu e deloc recomandat.
Cred ca era vorba de aceasta regula:

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

Poti aplica asa cum zice si in observatie ,via-stitching langa modulul esp32 .
Ai optiune sa folosesti o forma de poligon pentru Via Stitching (vezi la tip)   ( **NU** _cover entire board_ ).

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

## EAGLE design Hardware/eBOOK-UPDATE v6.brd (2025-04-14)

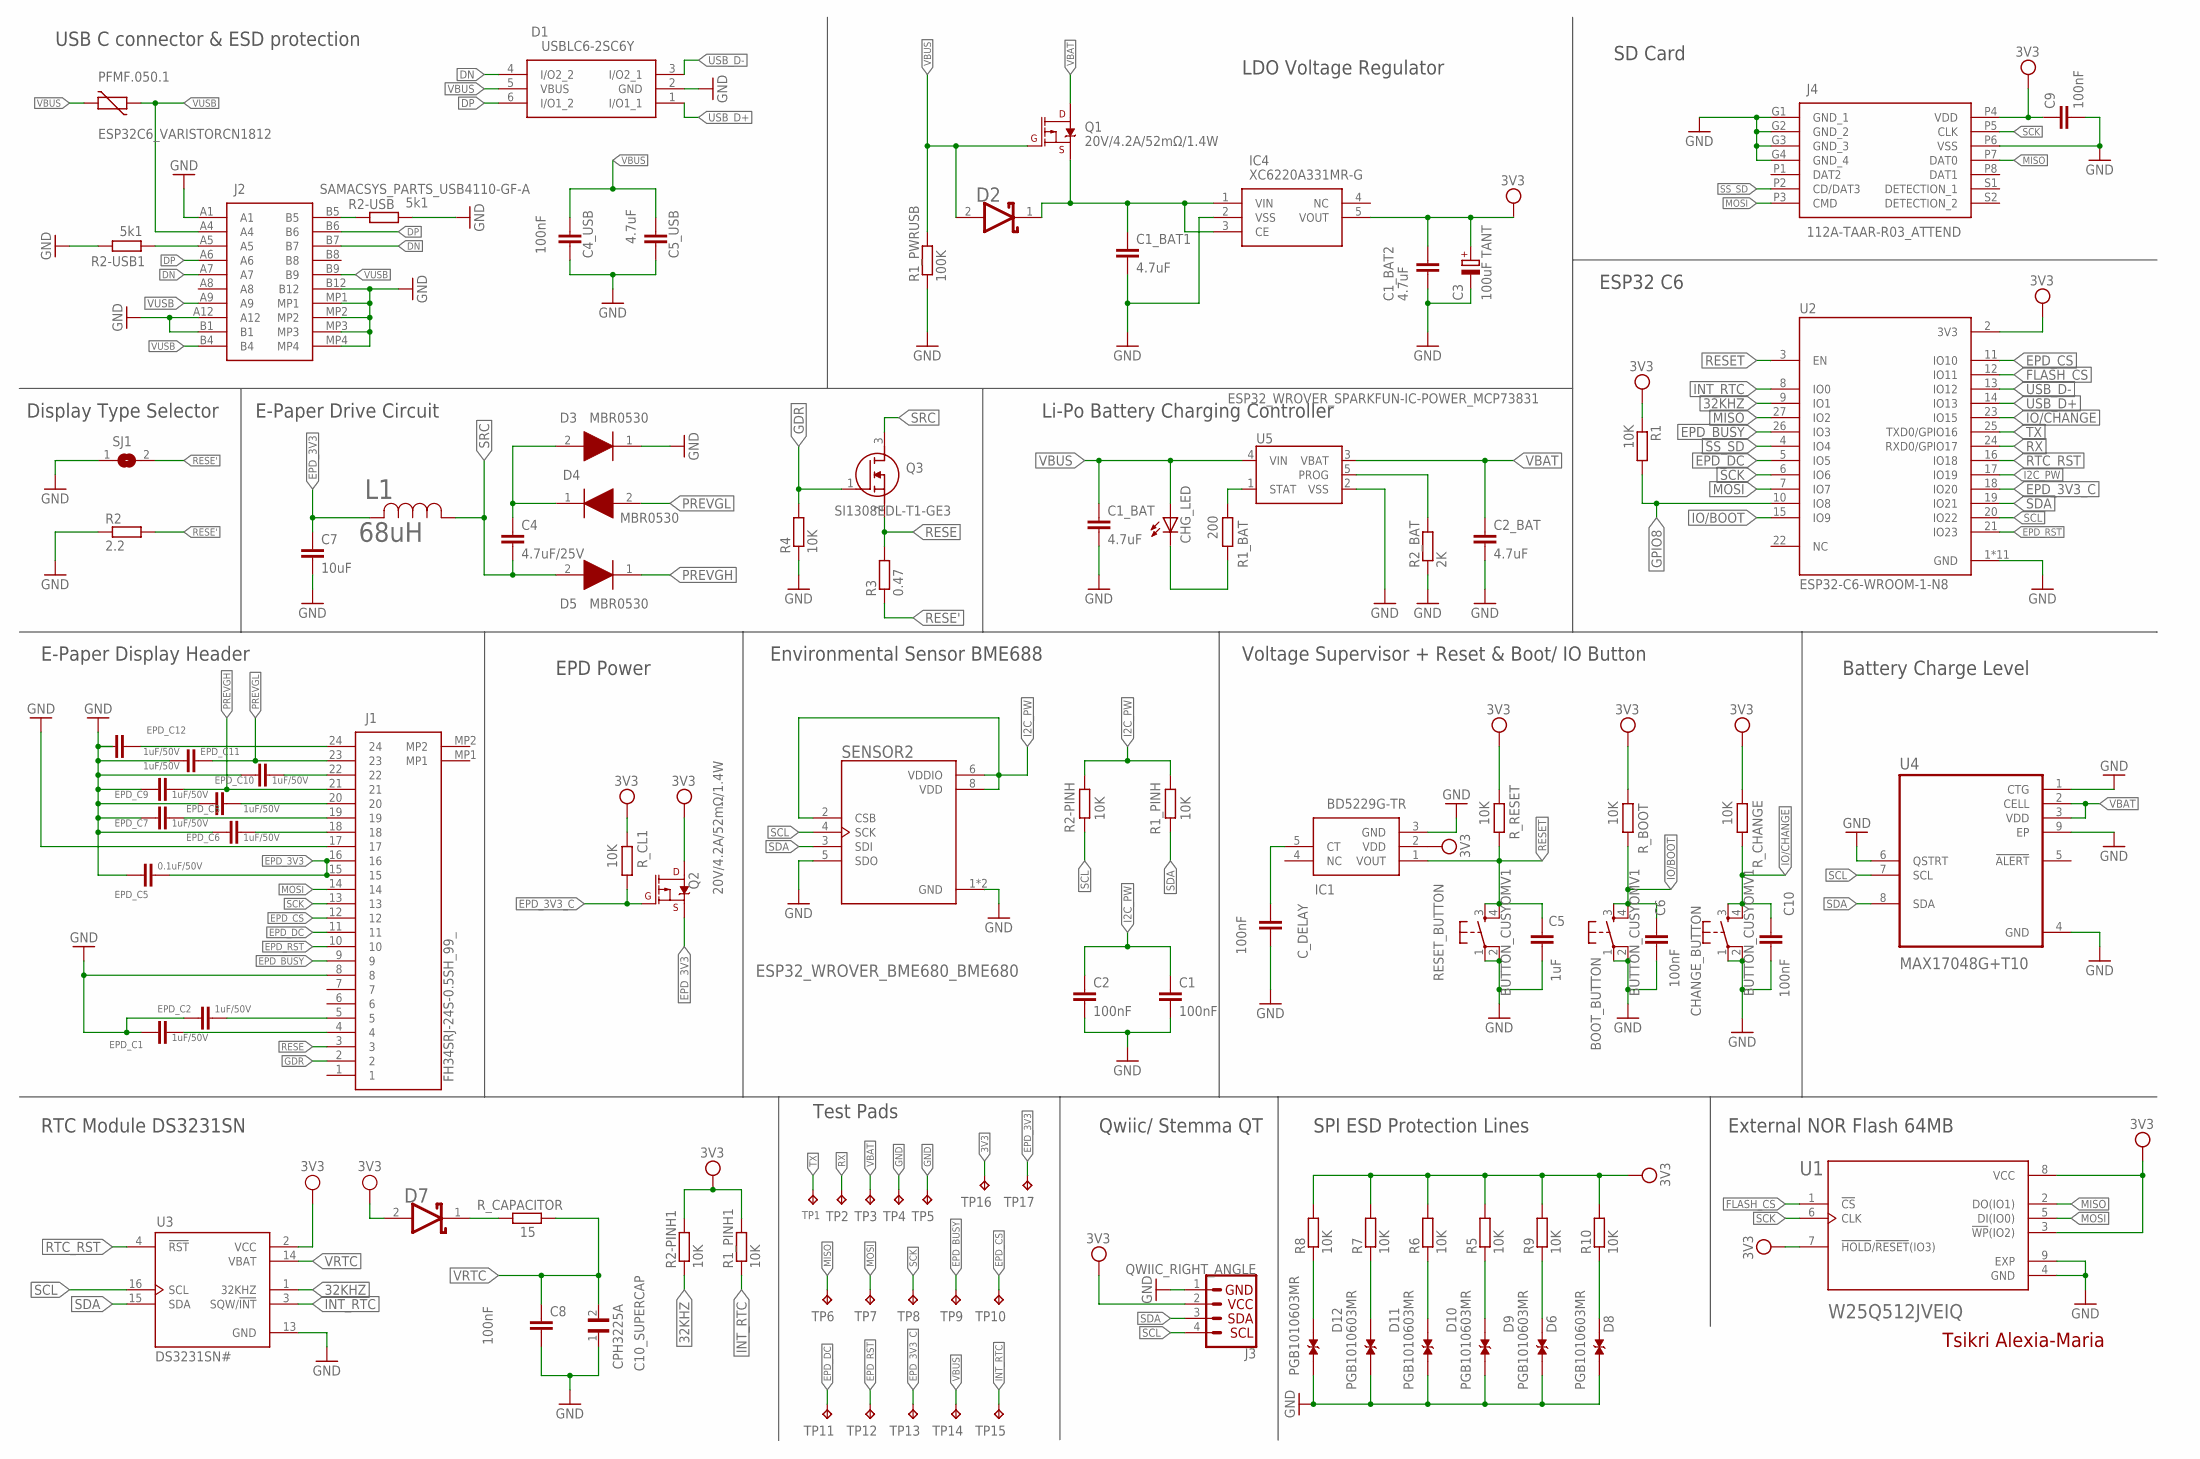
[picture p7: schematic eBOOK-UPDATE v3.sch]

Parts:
BOOT_BUTTON: BUTTON_CUSYOMV1; MYBUTTON
C1, C2, C4_USB, C6, C8, C9, C10: 100nF; ESP32_WROVER_EAGLE-LTSPICE_C0402
C1_BAT, C1_BAT1, C1_BAT2, C2_BAT, C5_USB: 4.7uF; ESP32_WROVER_EAGLE-LTSPICE_C0402
C3: 100uF TANT; RCL_CT3528
C4: 4.7uF/25V; ESP32_WROVER_EAGLE-LTSPICE_C0402
C5: 1uF; ESP32_WROVER_EAGLE-LTSPICE_C0402
C7: 10uF; ESP32_WROVER_EAGLE-LTSPICE_C0402
C10_SUPERCAP: CPH3225A; CAPCP3225X100N
CHANGE_BUTTON: BUTTON_CUSYOMV1; MYBUTTON
CHG_LED: ADAFRUIT_LEDCHIP-LED0603; ADAFRUIT_CHIP-LED0603
C_DELAY: 100nF; ESP32_WROVER_EAGLE-LTSPICE_C0402
D1: USBLC6-2SC6Y; SOT95P280X145-6N
D2, D7: ESP32_WROVER_AVX---SD0805S020S1R0_AVX_SD0805S020S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; ESP32_WROVER_AVX---SD0805S020S1R0_AVX_SD0805S020S1R0_0
D3, D4, D5: MBR0530; SOD3716X135N
D6, D8, D9, D10, D11, D12: PGB1010603MR; DIOC1608X36N
EPD_C1, EPD_C2, EPD_C6, EPD_C7, EPD_C8, EPD_C9, EPD_C10, EPD_C11, EPD_C12: 1uF/50V; ESP32_WROVER_EAGLE-LTSPICE_C0402
EPD_C5: 0.1uF/50V; ESP32_WROVER_EAGLE-LTSPICE_C0402
IC1: BD5229G-TR; SOT95P280X125-5N
IC4: XC6220A331MR-G; SOT95P280X120-5N
J1: FH34SRJ-24S-0.5SH_99_; FH34SRJ24S05SH99
J2: SAMACSYS_PARTS_USB4110-GF-A; SAMACSYS_PARTS_USB4110GFA
J3: QWIIC_RIGHT_ANGLE; JST04_1MM_RA
J4: 112A-TAAR-R03_ATTEND; 112ATAARR03ATTEND
L1: 68uH; IND_4828-WE-TPC_WRE
PFMF.050.1: ESP32C6_VARISTORCN1812; ESP32C6_VARISTOR_CT/CN1812
Q1, Q2: 20V/4.2A/52mΩ/1.4W; ESP32_WROVER_SPARKFUN-DISCRETESEMI_SOT23-3
Q3: SI1308EDL-T1-GE3; SOT65P210X110-3N
R1, R1_PINH, R1_PINH1, R2-PINH, R2-PINH1, R4, R5, R6, R7, R8, R9, R10: 10K; ESP32_WROVER_EAGLE-LTSPICE_R0402
R1_BAT: 200; ESP32_WROVER_EAGLE-LTSPICE_R0402
R1_PWRUSB: 100K; ESP32_WROVER_EAGLE-LTSPICE_R0402
R2: 2.2; ESP32_WROVER_EAGLE-LTSPICE_R0402
R2-USB, R2-USB1: 5k1; ESP32_WROVER_EAGLE-LTSPICE_R0402
R2_BAT: 2K; ESP32_WROVER_EAGLE-LTSPICE_R0402
R3: 0.47; ESP32_WROVER_EAGLE-LTSPICE_R0402
RESET_BUTTON: BUTTON_CUSYOMV1; MYBUTTON
R_BOOT: 10K; ESP32_WROVER_EAGLE-LTSPICE_R0402
R_CAPACITOR: 15; ESP32_WROVER_EAGLE-LTSPICE_R0402
R_CHANGE: 10K; ESP32_WROVER_EAGLE-LTSPICE_R0402
R_CL1: 10K; ESP32_WROVER_EAGLE-LTSPICE_R0402
R_RESET: 10K; ESP32_WROVER_EAGLE-LTSPICE_R0402
SENSOR2: ESP32_WROVER_BME680_BME680; ESP32_WROVER_BME680_PSON80P300X300X100-8N
SJ1: SJ
TP1, TP2, TP3, TP4, TP5, TP6, TP7, TP8, TP9, TP10, TP11, TP12, TP13, TP14, TP15, TP16, TP17: TPTP20R; TP20R
U1: W25Q512JVEIQ; SON127P600X800X80-9N
U2: ESP32-C6-WROOM-1-N8; XCVR_ESP32-C6-WROOM-1-N8
U3: DS3231SN#; SOIC127P1032X265-16N
U4: MAX17048G+T10; SON50P200X200X80-9N
U5: ESP32_WROVER_SPARKFUN-IC-POWER_MCP73831; ESP32_WROVER_SPARKFUN-IC-POWER_SOT23-5

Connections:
3V3: C1_BAT2.1, C3.+, C9.1, D7.2 (ANODE), IC1.2 (VDD), IC4.5 (VOUT), J3.2, J4.P4 (VDD), Q2.3 (D), R1.1, R1_PINH1.2, R2-PINH1.2, R5.2, R6.2, R7.2, R8.2, R9.2, R10.2, R_BOOT.2, R_CHANGE.2, R_CL1.2, R_RESET.2, TP16.TP, U1.3 (!WP!(IO2)), U1.7 (!HOLD!/!RESET!(IO3)), U1.8 (VCC), U2.2 (3V3), U3.2 (VCC)
32KHZ: R2-PINH1.1, U2.9 (IO1), U3.1 (32KHZ)
DN: D1.4 (I/O2_2), J2.A7, J2.B7
DP: D1.6 (I/O1_2), J2.A6, J2.B6
EPD_3V3: C7.1, EPD_C5.1, J1.15, J1.16, L1.2, Q2.2 (S), TP17.TP
EPD_3V3_C: Q2.1 (G), R_CL1.1, TP13.TP, U2.18 (IO20)
EPD_BUSY: J1.9, TP9.TP, U2.26 (IO3)
EPD_CS: J1.12, TP10.TP, U2.11 (IO10)
EPD_DC: J1.11, TP11.TP, U2.5 (IO5)
EPD_RST: J1.10, TP12.TP, U2.21 (IO23)
FLASH_CS: U1.1 (!CS), U2.12 (IO11)
GDR: J1.2, Q3.1 (G), R4.2
GND: BOOT_BUTTON.1, BOOT_BUTTON.2, C1.2, C1_BAT.2, C1_BAT1.2, C1_BAT2.2, C2.2, C2_BAT.2, C3.-, C4_USB.2, C5.2, C5_USB.2, C6.2, C7.2, C8.2, C9.2, C10.2, C10_SUPERCAP.1, CHANGE_BUTTON.1, CHANGE_BUTTON.2, C_DELAY.2, D1.2 (GND), D3.1 (K), D6.1, D8.1, D9.1, D10.1, D11.1, D12.1, EPD_C1.2, EPD_C2.2, EPD_C5.2, EPD_C6.2, EPD_C7.2, EPD_C8.2, EPD_C9.2, EPD_C10.2, EPD_C11.2, EPD_C12.2, IC1.3 (GND), IC4.2 (VSS), J1.8, J1.17, J2.A1, J2.A12, J2.B1, J2.B12, J2.MP1, J2.MP2, J2.MP3, J2.MP4, J3.1, J4.G1 (GND_1), J4.G2 (GND_2), J4.G3 (GND_3), J4.G4 (GND_4), J4.P6 (VSS), R1_PWRUSB.1, R2.1, R2-USB.2, R2-USB1.1, R2_BAT.1, R4.1, RESET_BUTTON.1, RESET_BUTTON.2, SENSOR2.1 (GND), SENSOR2.5 (SDO), SENSOR2.7 (GND), SJ1.1, TP4.TP, TP5.TP, U1.4 (GND), U1.9 (EXP), U2.1 (GND), U2.28 (GND), U2.29_1 (GND), U2.29_2 (GND), U2.29_3 (GND), U2.29_4 (GND), U2.29_5 (GND), U2.29_6 (GND), U2.29_7 (GND), U2.29_8 (GND), U2.29_9 (GND), U3.13 (GND), U4.1 (CTG), U4.4 (GND), U4.6 (QSTRT), U4.9 (EP), U5.2 (VSS)
GPIO8: R1.2, U2.10 (IO8)
I2C_PW: C1.1, C2.1, R1_PINH.1, R2-PINH.1, SENSOR2.2 (CSB), SENSOR2.6 (VDDIO), SENSOR2.8 (VDD), U2.17 (IO19)
INT_RTC: R1_PINH1.1, TP15.TP, U2.8 (IO0), U3.3 (SQW/!INT)
IO/BOOT: BOOT_BUTTON.3, BOOT_BUTTON.4, C6.1, R_BOOT.1, U2.15 (IO9)
IO/CHANGE: C10.1, CHANGE_BUTTON.3, CHANGE_BUTTON.4, R_CHANGE.1, U2.23 (IO15)
MISO: J4.P7 (DAT0), TP6.TP, U1.2 (DO(IO1)), U2.27 (IO2)
MOSI: J1.14, J4.P3 (CMD), TP7.TP, U1.5 (DI(IO0)), U2.7 (IO7)
unnamed: D7.1 (CATHODE), R_CAPACITOR.1
unnamed: D8.2, R10.1
unnamed: D6.2, R9.1
unnamed: D9.2, R5.1
unnamed: D10.2, R6.1
unnamed: D11.2, R7.1
unnamed: D12.2, R8.1
unnamed: C_DELAY.1, IC1.5 (CT)
unnamed: J2.A5, R2-USB1.2
unnamed: C1_BAT1.1, D2.1 (CATHODE), IC4.1 (VIN), IC4.3 (CE), Q1.2 (S)
unnamed: R1_BAT.2, U5.1 (STAT)
unnamed: CHG_LED.C, R1_BAT.1
unnamed: J2.B5, R2-USB.1
unnamed: R2_BAT.2, U5.5 (PROG)
unnamed: EPD_C10.1, J1.22
unnamed: C4.1, D3.2 (A), D4.1 (K)
unnamed: EPD_C12.1, J1.24
unnamed: EPD_C8.1, J1.20
unnamed: EPD_C7.1, J1.19
unnamed: EPD_C6.1, J1.18
unnamed: EPD_C2.1, J1.5
unnamed: EPD_C1.1, J1.4
PREVGH: D5.1 (K), EPD_C9.1, J1.21
PREVGL: D4.2 (A), EPD_C11.1, J1.23
RESE: J1.3, Q3.2 (S), R3.2
RESE': R2.2, R3.1, SJ1.2
RESET: C5.1, IC1.1 (VOUT), RESET_BUTTON.3, RESET_BUTTON.4, R_RESET.1, U2.3 (EN)
RTC_RST: U2.16 (IO18), U3.4 (!RST)
RX: TP2.TP, U2.24 (RXD0/GPIO17)
SCK: J1.13, J4.P5 (CLK), TP8.TP, U1.6 (CLK), U2.6 (IO6)
SCL: J3.4, R2-PINH.2, SENSOR2.4 (SCK), U2.20 (IO22), U3.16 (SCL), U4.7 (SCL)
SDA: J3.3, R1_PINH.2, SENSOR2.3 (SDI), U2.19 (IO21), U3.15 (SDA), U4.8 (SDA)
SRC: C4.2, D5.2 (A), L1.1, Q3.3 (D)
SS_SD: J4.P2 (CD/DAT3), U2.4 (IO4)
TX: TP1.TP, U2.25 (TXD0/GPIO16)
USB_D+: D1.1 (I/O1_1), U2.14 (IO13)
USB_D-: D1.3 (I/O2_1), U2.13 (IO12)
VBAT: C2_BAT.1, Q1.3 (D), TP3.TP, U4.2 (CELL), U4.3 (VDD), U5.3 (VBAT)
VBUS: C1_BAT.1, C4_USB.1, C5_USB.1, CHG_LED.A, D1.5 (VBUS), D2.2 (ANODE), PFMF.050.1.2, Q1.1 (G), R1_PWRUSB.2, TP14.TP, U5.4 (VIN)
VRTC: C8.1, C10_SUPERCAP.2, R_CAPACITOR.2, U3.14 (VBAT)
VUSB: J2.A4, J2.A9, J2.B4, J2.B9, PFMF.050.1.1

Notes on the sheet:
External NOR Flash 64MB
SPI ESD Protection Lines
Qwiic/ Stemma QT
Test Pads
RTC Module DS3231SN
USB C connector & ESD protection
LDO Voltage Regulator
SD Card
ESP32 C6
Li-Po Battery Charging Controller
E-Paper Drive Circuit
Display Type Selector
E-Paper Display Header
EPD Power
Environmental Sensor BME688
Voltage Supervisor + Reset & Boot/ IO Button
Battery Charge Level
Tsikri Alexia-Maria

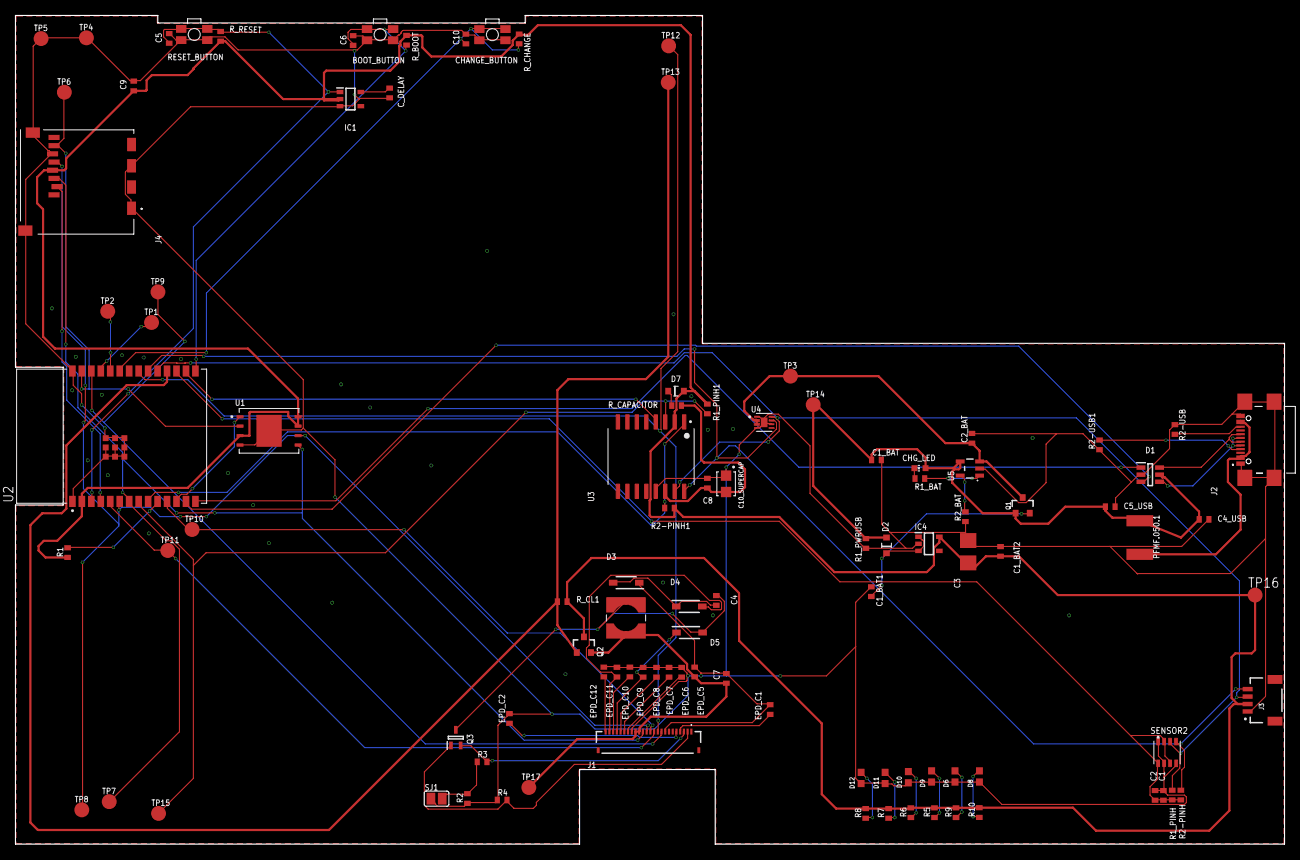
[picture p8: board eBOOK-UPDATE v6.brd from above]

Board: 2 copper layers, 170.3 x 111.2 mm, 103 parts (0 on the bottom side), 61 nets.

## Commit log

2025-04-06 Create OpenBook Enclosure v10.f3z
2025-04-14 update v2
    [eBOOK v35.brd, eBOOK-UPDATE v3.sch, eBOOK-UPDATE v6.brd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]

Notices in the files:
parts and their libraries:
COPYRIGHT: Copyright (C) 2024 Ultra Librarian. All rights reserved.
